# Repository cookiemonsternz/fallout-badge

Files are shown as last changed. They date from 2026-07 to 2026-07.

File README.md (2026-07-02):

# Fallout Badge - SYNTH

Woah! A badge :O

## What is it?!

A badge with holes for mounting to a lanyard, containing within a full miniature analogue synthesizer / sequencer. 
This badge has a sawtooth vco core, with mcu controlled pitch and a manually controlled filter (modelled off of the Big Muff PI tone stage).

It also includes a small interface for playing and step recording a note sequence.

## Limitations

Due to the form factor / component limitations, this synth isn't fully featured, namely:
- It lacks a VCA (When its on it will constantly make noise)
- Untunable / no temperature compensation (Notes will be in tune with each other, but you'll only be able to tune it via software)
- Probably quite noisy and bad sounding - buzzers suck
  
## Screenshots

Schematic
PCB
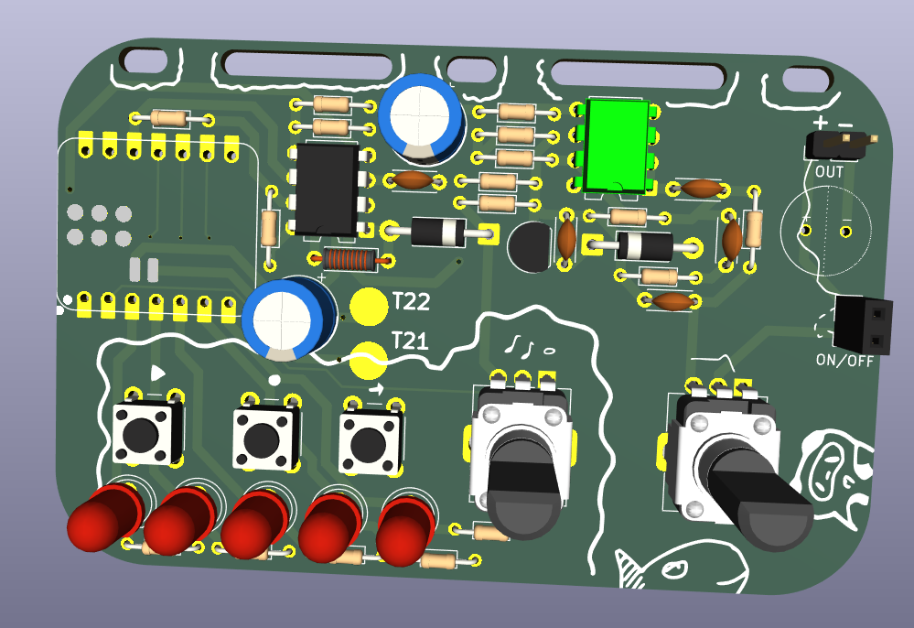
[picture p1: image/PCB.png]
PCB 3D


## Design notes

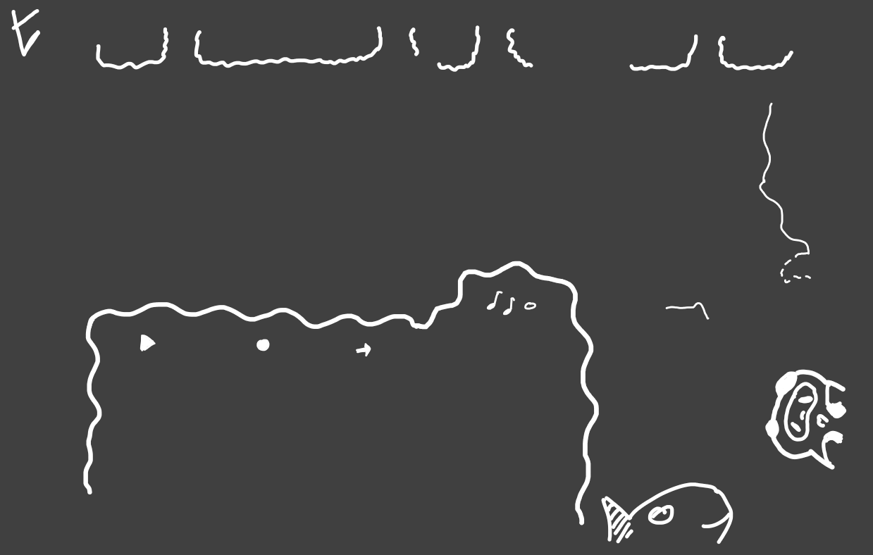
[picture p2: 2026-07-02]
silkscreen.png

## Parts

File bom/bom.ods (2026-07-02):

Item | Qty | Source | Cost
PCB | 5 | JLCPCB | $2.00
Xiao ESP32-C3 | 1 | Fallout | $0.00
MC34063AP | 1 | Huaqiangbei / LCSC | $1.00
TL072 | 1 | Huaqiangbei / LCSC | $0.47
Speaker | 1 | Fallout | $0.00
LED | 5 | Fallout | $0.00
220r Resistor | 5 | Fallout | $0.00
Other Resistors | 12 | Fallout | $0.00
Other Capacitors | 6 | Fallout | $0.00
170uH Inductor | 1 | Huaqiangbei / LCSC | $0.15
1N5819 Schottky Diode | 2 | Fallout | $0.00
SW Push | 3 | Fallout | $0.00
Potentiometer | 2 | Fallout | $0.00
NPN BJT | 1 | Fallout | $0.00

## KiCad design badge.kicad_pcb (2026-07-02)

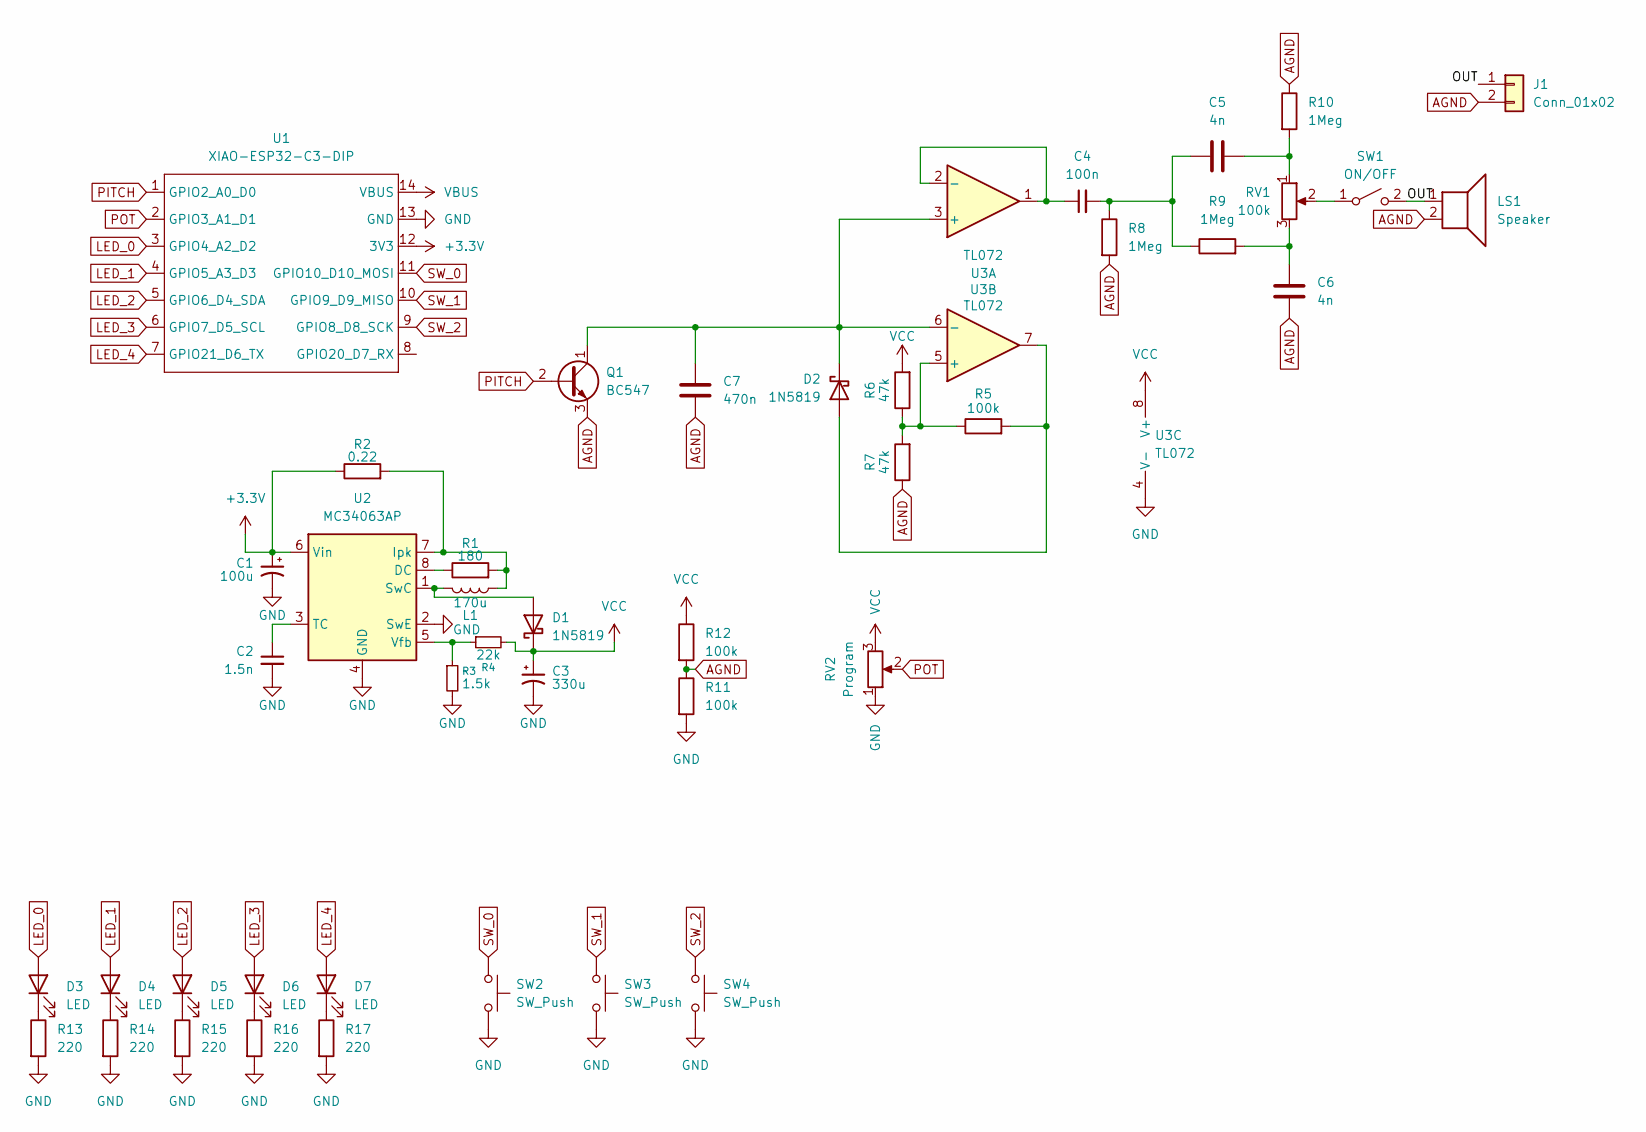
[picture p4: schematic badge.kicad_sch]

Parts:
C1: 100u; CP_Radial_D8.0mm_P3.50mm
C2: 1.5n; C_Disc_D4.3mm_W1.9mm_P5.00mm
C3: 330u; CP_Radial_D8.0mm_P3.50mm
C4: 100n; C_Disc_D4.3mm_W1.9mm_P5.00mm
C5, C6: 4n; C_Disc_D4.3mm_W1.9mm_P5.00mm
C7: 470n; C_Disc_D4.3mm_W1.9mm_P5.00mm
D1, D2: 1N5819; D_DO-41_SOD81_P10.16mm_Horizontal
D3, D4, D5, D6, D7: LED; LED_D5.0mm
J1: Conn_01x02; PinHeader_1x02_P2.54mm_Vertical
L1: 170u; L_Axial_L5.3mm_D2.2mm_P7.62mm_Horizontal_Vishay_IM-1
LS1: Speaker; Speaker-4mm
Q1: BC547; TO-92_Inline
R1: 180; R_Axial_DIN0204_L3.6mm_D1.6mm_P7.62mm_Horizontal
R2: 0.22; R_Axial_DIN0204_L3.6mm_D1.6mm_P7.62mm_Horizontal
R3: 1.5k; R_Axial_DIN0204_L3.6mm_D1.6mm_P7.62mm_Horizontal
R4: 22k; R_Axial_DIN0204_L3.6mm_D1.6mm_P7.62mm_Horizontal
R5, R11, R12: 100k; R_Axial_DIN0204_L3.6mm_D1.6mm_P7.62mm_Horizontal
R6, R7: 47k; R_Axial_DIN0204_L3.6mm_D1.6mm_P7.62mm_Horizontal
R8, R9, R10: 1Meg; R_Axial_DIN0204_L3.6mm_D1.6mm_P7.62mm_Horizontal
R13, R14, R15, R16, R17: 220; R_Axial_DIN0204_L3.6mm_D1.6mm_P7.62mm_Horizontal
RV1: 100k; Potentiometer_Alps_RK09K_Single_Vertical
RV2: Program; Potentiometer_Alps_RK09K_Single_Vertical
SW1: ON/OFF; PinSocket_1x02_P2.54mm_Vertical
SW2, SW3, SW4: SW_Push; SW_PUSH_6mm
U1: XIAO-ESP32-C3-DIP; XIAO-ESP32-C3-DIP-SMD
U2: MC34063AP; DIP-8_W7.62mm
U3: TL072; DIP-8_W7.62mm

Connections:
+3.3V: C1.1, R2.1, U1.12 (3V3), U2.6 (Vin)
/OUT: J1.1, LS1.1, SW1.2 (B); also elsewhere on the board
AGND: C6.1, C7.2, J1.2, LS1.2, Q1.3 (E), R7.1, R8.2, R10.1, R11.1, R12.2; also elsewhere on the board
GND: C1.2, C2.2, C3.2, R3.2, R11.2, R13.2, R14.2, R15.2, R16.2, R17.2, RV2.1, SW2.2, SW3.2, SW4.2, U1.13 (GND), U2.2 (SwE), U2.4 (GND), U3.4 (V-)
LED_0: D3.2 (A), U1.3 (GPIO4_A2_D2)
LED_1: D4.2 (A), U1.4 (GPIO5_A3_D3)
LED_2: D5.2 (A), U1.5 (GPIO6_D4_SDA)
LED_3: D6.2 (A), U1.6 (GPIO7_D5_SCL)
LED_4: D7.2 (A), U1.7 (GPIO21_D6_TX)
unnamed: C4.2, C5.1, R8.1, R9.1
unnamed: C5.2, R10.2, RV1.1
unnamed: C6.2, R9.2, RV1.3
unnamed: D1.2 (A), L1.1, U2.1 (SwC)
unnamed: D2.2 (A), R5.2, U3.7
unnamed: C7.1, D2.1 (K), Q1.1 (C), U3.3 (+), U3.6 (-)
unnamed: D3.1 (K), R13.1
unnamed: D4.1 (K), R14.1
unnamed: D5.1 (K), R15.1
unnamed: D6.1 (K), R16.1
unnamed: D7.1 (K), R17.1
unnamed 20: RV1.2, SW1.1 (A); also elsewhere on the board
unnamed: R1.1, U2.8 (DC)
unnamed: L1.2, R1.2, R2.2, U2.7 (Ipk)
unnamed: C2.1, U2.3 (TC)
unnamed: R3.1, R4.1, U2.5 (Vfb)
unnamed: C4.1, U3.1, U3.2 (-)
unnamed: R5.1, R6.1, R7.2, U3.5 (+)
PITCH: Q1.2 (B), U1.1 (GPIO2_A0_D0)
POT: RV2.2, U1.2 (GPIO3_A1_D1)
SW_0: SW2.1, U1.11 (GPIO10_D10_MOSI)
SW_1: SW3.1, U1.10 (GPIO9_D9_MISO)
SW_2: SW4.1, U1.9 (GPIO8_D8_SCK)
VBUS: U1.14 (VBUS)
VCC: C3.1, D1.1 (K), R4.2, R6.2, R12.1, RV2.3, U3.8 (V+)

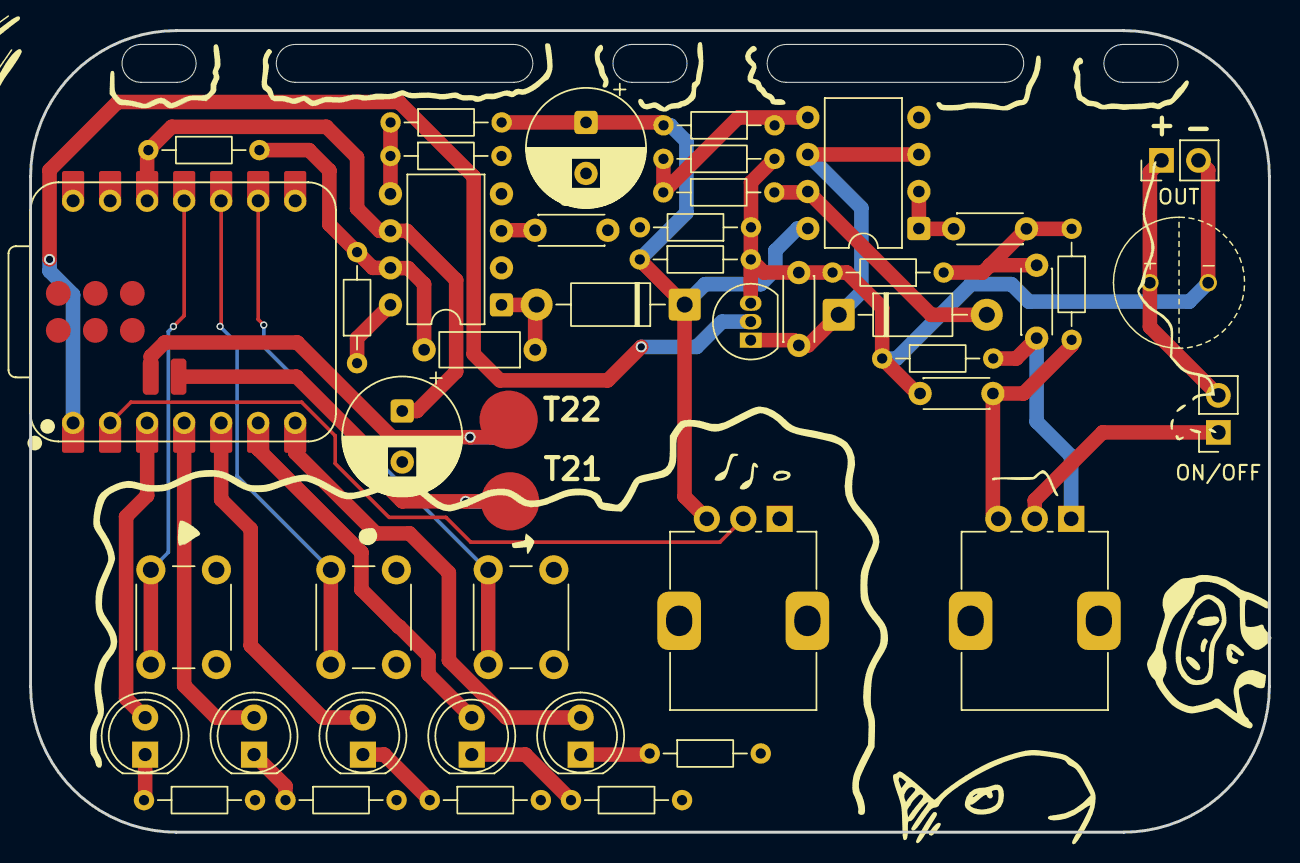
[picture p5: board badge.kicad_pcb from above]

Board: 2 copper layers, 85.0 x 55.0 mm, 44 parts (0 on the bottom side), 33 nets.

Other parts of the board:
ON/OFF: ON/OFF; PinSocket_1x02_P2.54mm_Vertical
OUT: Conn_01x02; PinHeader_1x02_P2.54mm_Vertical

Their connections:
/OUT: ON/OFF.2 (B), OUT.1; also elsewhere on the board
AGND: OUT.2; also elsewhere on the board
unnamed 20: ON/OFF.1 (A); also elsewhere on the board
